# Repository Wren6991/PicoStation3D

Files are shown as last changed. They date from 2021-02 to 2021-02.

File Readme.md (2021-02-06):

PicoStation 3D
==============

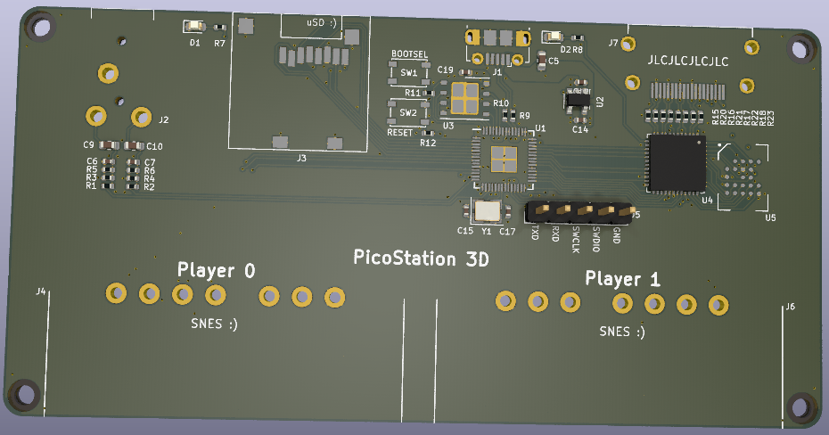
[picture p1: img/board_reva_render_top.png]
Top view of board, showing an RP2040 microcontroller, iCE40 UP5k FPGA, 8MB HyperRAM, HDMI socket, micro SD receptacle, audio jack, two SNES controller ports, micro USB for power + data.


This is an **unfinished, untested** project to develop a 3D games console based on an RP2040 microcontroller and an iCE40 UP5k FPGA. Quick links:

- [Board Schematic (PDF)](board/picostation.pdf)
- [RP2040 Datasheet (PDF)](https://datasheets.raspberrypi.org/rp2040/rp2040-datasheet.pdf)
- [FPGA Datasheet (PDF)](http://www.latticesemi.com/-/media/LatticeSemi/Documents/DataSheets/iCE/iCE40-UltraPlus-Family-Data-Sheet.ashx)

From left to right, the components on the top edge are:

- A 3.5mm TRS audio jack, connected straight to RP2040 GPIOs via an RC filter (no separate audio supply on this board rev)
- A status LED for the RP2040
- A micro SD receptacle connected to the RP2040
- A micro USB socket providing power to the board, and code download and serial comms via the RP2040
- A status LED for the FPGA
- An HDMI socket for DVI-D video output, connected to the FPGA

The bottom edge has two SNES controller sockets. Also on the board is an 8MiB HyperRAM connected to the FPGA.

There is a RESET and BOOTSEL button for the RP2040, for quick firmware updates over USB, but the debug header (UART + SWD) is a better solution for iterating and developing code.

There are 12 wires connecting the FPGA to the microcontroller, one of them going from a GPOUT clock output on the RP2040 to a GB_IN global clock input pin on the UP5k. The intention is to use these for an 8 bit parallel bus with a free-running clock, a valid-ready handshake and an IRQ line, and for the UP5k to derive its internal clocks from the bus clock. This interface overlaps with the pins required to load the FPGA's internal configuration memory (and the RP2040 also has control of the UP5k's reset) so there is no separate external flash required for the UP5k.

Board Use Cases
---------------

- Run everything, including graphics routines, on RP2040, and use the UP5k as a parallel to DVI-D bridge -- [see here for a quick demo of some scanline blitting on RP2040](https://twitter.com/wren6991/status/1352983731661926401?s=20)

- Run everything, including a soft processor, on the UP5k, and use RP2040 as a surprisingly cost-effective USB-serial bridge, as well as for firmware upload. You'll need some kind of shell running on the RP2040 to provide audio and controller port access from the FPGA

- Run game logic, audio, controller access and SD card access on RP2040, put all the graphics hardware in the UP5k (with the local 8MB HyperRAM as VRAM, plus the UP5k's internal 128k SPRAM)

- Run 3D vertex-side operations on RP2040, and put 3D fragment-side hardware on the FPGA

Project Status
--------------

I've laid out a first iteration of the board, and have soldered up a prototype, but haven't had the chance to bring up the board or write any firmware, thanks to being a bit overloaded with the launch of RP2040 itself!

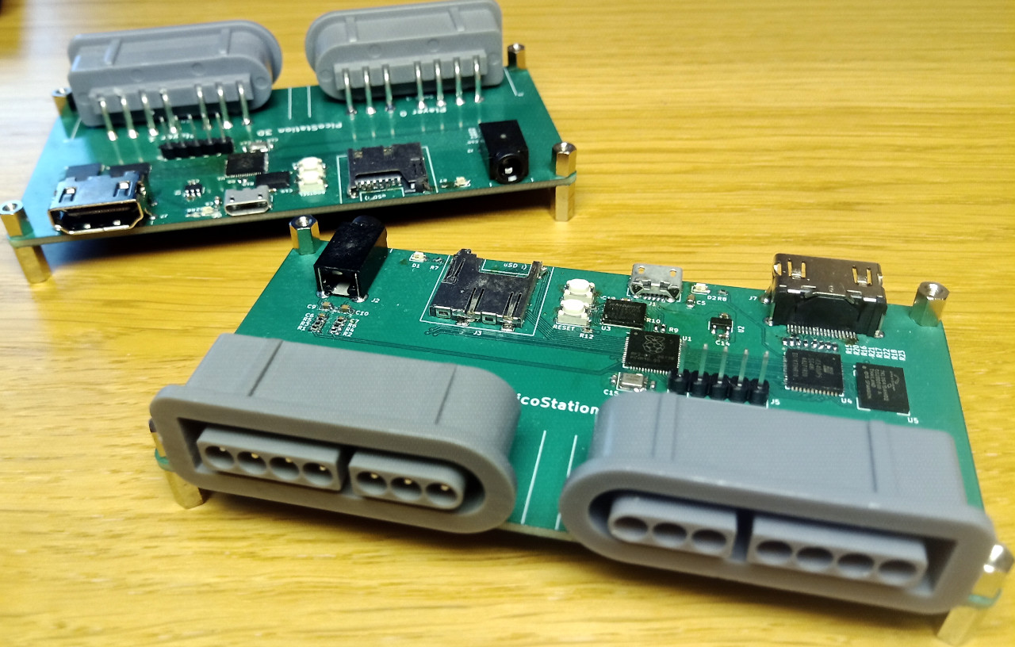
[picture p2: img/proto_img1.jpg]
Front view of a prototype board, showing the two SNES controller connectors soldered to the front


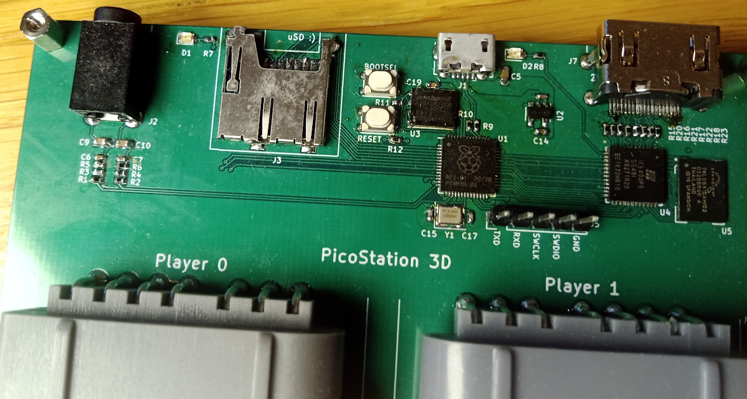
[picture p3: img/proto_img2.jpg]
Top detail of a prototype board, showing the RP2040 microcontroller, iCE40 UP5k FPGA, and HyperRAM. The controller ports are labelled player 0 and player 1.


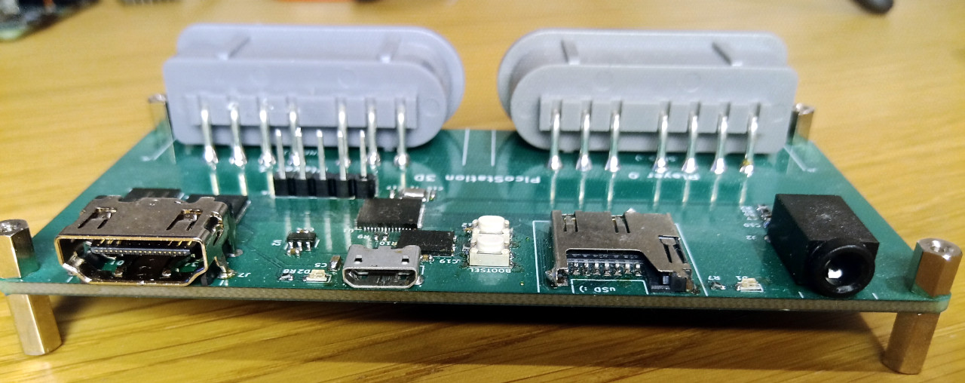
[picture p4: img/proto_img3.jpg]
Rear view of a prototype board, showing left to right the HDMI socket, FPGA LED, USB socket, SD card slot, microcontroller LED, and audio jack.


There are questionable decisions in [the schematic](board/picostation.pdf) (in particular the power chain violates the UP5k's sequencing requirements) so you shouldn't copy what you see here, but I'm posting this anyway because it might inspire somebody to make something better, and that is more important than me being embarrassed about my shoddy design work.

You can find a proof of concept for direct DVI output from a UP5k FPGA [in this repo](https://github.com/Wren6991/smoldvi).

I've also managed to squeeze [RISCBoy](https://github.com/Wren6991/RISCBoy) plus a DVI output onto a UP5k. Still need to push that code but you can see [a video of it I tweeted](https://twitter.com/wren6991/status/1348722305720004608?s=20). This shows you can fit plenty of interesting graphics hardware (and in this case a RISC-V processor) into a UP5k whilst generating DVI-D signals.

Known issues with rev A:

- Digital supply noise is audible through the audio jack. This could be improved by a separate LDO'd audio supply with a dual logic buffer, or just by deleting this output and doing digital audio through the video connector on the FPGA.
- The FPGA core supply comes from RP2040's LDO, to try and keep part count to an absolute minimum. This gives a fast ramp to 1.1 V shortly *after* the 3.3 V IO supply comes up, and a second ramp to 1.2 V some milliseconds later when software adjusts RP2040's core regulator. This is all quite questionable, and part of the point of Rev A is to find out whether I can get away with this.
- The controllers are only accessible from RP2040, not the FPGA. This is not a huge issue, but it would be more fun as an FPGA platform if they were moved to the FPGA, or perhaps even make the CLK and LAT line open-drain, and connect the controllers to both FPGA *and* RP2040.
- There is no separate configuration flash for the FPGA. Instead the microcontroller stores the bitstream in its flash, and writes this into the FPGA's configuration memory at boot. This should work fine but it's a less familiar development flow for those using this as an FPGA board, and it might be nice for pure-FPGA games consoles to have some local flash to access. Again, I'm trying to see how little hardware I can get away with, and this might have been a misstep.
- The SNES controller sockets are transposed left-to-right compared with an actual SNES.
- Double-sided component load makes it annoying to reflow this board at home, and adds cost if you want to get it PCBA'd.

If you have read all the way to the end and you have spotted something else that irritates you about this design, please [raise an issue!](/../../issues/) It will be a while until I get to Rev B. The main purpose of Rev A was to explore what I could get away with, and to develop the comms and interactions between microcontroller and FPGA.

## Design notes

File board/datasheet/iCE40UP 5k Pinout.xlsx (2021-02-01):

# Pin Out For iCE5UP5K (iCE40 UltraPlus - 5K)
# Revision 0.4 - Remove FWG49
# Revision 1.1 - Fix RGB pins, swapped C5 & A5 pins as well as 39 & 41
# Updated Jun 19, 2017
FNC | Pin Type | BANK | Differential Pair | UWG30 | SG48
IOB_0a | PIO | 2 |  | E5 | 46
IOB_2a | DPIO | 2 | TRUE_of_IOB_3b | D5 | 47
IOB_3b_G6 | DPIO/GBIN | 2 | COMP_of_IOB_2a | F5 | 44
IOB_4a | DPIO | 2 | TRUE_of_IOB_5b | - | 48
IOB_5b | DPIO | 2 | COMP_of_IOB_4a | - | 45
IOB_6a | PIO | 2 |  | - | 2
IOB_8a | DPIO | 2 | TRUE_of_IOB_9b | - | 4
IOB_9b | DPIO | 2 | COMP_of_IOB_8a | E4 | 3
IOB_10a | DPIO | 1 | TRUE_of_IOB_11b | C3 | -
IOB_11b_G5 | DPIO/GBIN | 1 | COMP_of_IOB_10a | F4 | -
creset_b | CONFIG | 1 |  | F3 | 8
IOB_12a_G4_CDONE | CONFIG/DPIO/GBIN | 1 | TRUE_of_IOB_13b | D3 | -
CDONE | CONFIG | 1 |  | - | 7
IOB_13b | DPIO | 1 | COMP_of_IOB_12a | E3 | 6
IOB_16a | PIO | 1 |  | - | 9
IOB_18a | PIO | 1 |  | - | 10
IOB_20a | PIO | 1 |  | - | 11
IOB_22a | DPIO | 1 | TRUE_of_IOB_23b | - | 12
IOB_23b | DPIO | 1 | COMP_of_IOB_22a | - | 21
IOB_24a | DPIO | 1 | TRUE_of_IOB_25b | B1 | 13
IOB_25b_G3 | DPIO/GBIN | 1 | COMP_of_IOB_24a | F2 | 20
IOB_29b | PIO | 1 |  | - | 19
IOB_31b | PIO | 1 |  | - | 18
IOB_32a_SPI_SO | DPIO/CONFIG_SPI | 1 |  | F1 | 14
IOB_33b_SPI_SI | DPIO/CONFIG_SPI | 1 |  | E1 | 17
IOB_34a_SPI_SCK | DPIO/CONFIG_SPI | 1 |  | D1 | 15
IOB_35b_SPI_SS | DPIO/CONFIG_SPI | 1 |  | C1 | 16
VCCPLL | VCCPLL |  |  | B2 | 29
IOT_36b | DPIO/I3C | 0 | COMP_of_IOT_37a | A1 | 25
IOT_37a | DPIO/I3C | 0 | TRUE_of_IOT_36b | A2 | 23
IOT_38b | DPIO | 0 | COMP_of_IOT_39a | - | 27
IOT_39a | DPIO | 0 | TRUE_of_IOT_38b | - | 26
IOT_41a | PIO | 0 |  | - | 28
IOT_42b | DPIO | 0 | COMP_of_IOT_43a | - | 31
IOT_43a | DPIO | 0 | TRUE_of_IOT_42b | - | 32
IOT_44b | DPIO | 0 | COMP_of_IOT_45a | - | 34
IOT_45a_G1 | DPIO/GBIN | 0 | TRUE_of_IOT_44b | - | 37
IOT_46b_G0 | DPIO/GBIN | 0 |  | B3 | 35
IOT_47a | PIO | 0 |  | A4 | -
IOT_48b | DPIO | 0 | COMP_of_IOT_49a | - | 36
IOT_49a | DPIO | 0 | TRUE_of_IOT_48b | - | 43
IOT_50b | DPIO | 0 | COMP_of_IOT_51a | - | 38
IOT_51a | DPIO | 0 | TRUE_of_IOT_50b | - | 42
RGB2 | LED | 0 |  | C5 | 41
RGB1 | LED | 0 |  | B5 | 40
RGB0 | LED | 0 |  | A5 | 39
GND | GND | GND |  | B4 | Paddle
GND | GND | GND |  | E2 | Paddle
GND | GND | GND |  | - | Paddle
VCC | VCC | VCC |  | C2 | 5
VCC | VCC | VCC |  | - | 30
VCCIO_0 | VCCIO | 0 |  | A3 | 33
SPI_Vccio1 | VCCIO | 1 |  | D2 | 22
VCCIO_2 | VCCIO | 2 |  | C4 | 1
VPP_2V5 | VPP | VPP |  | D4 | 24
*SG48 GND is connected to package paddle

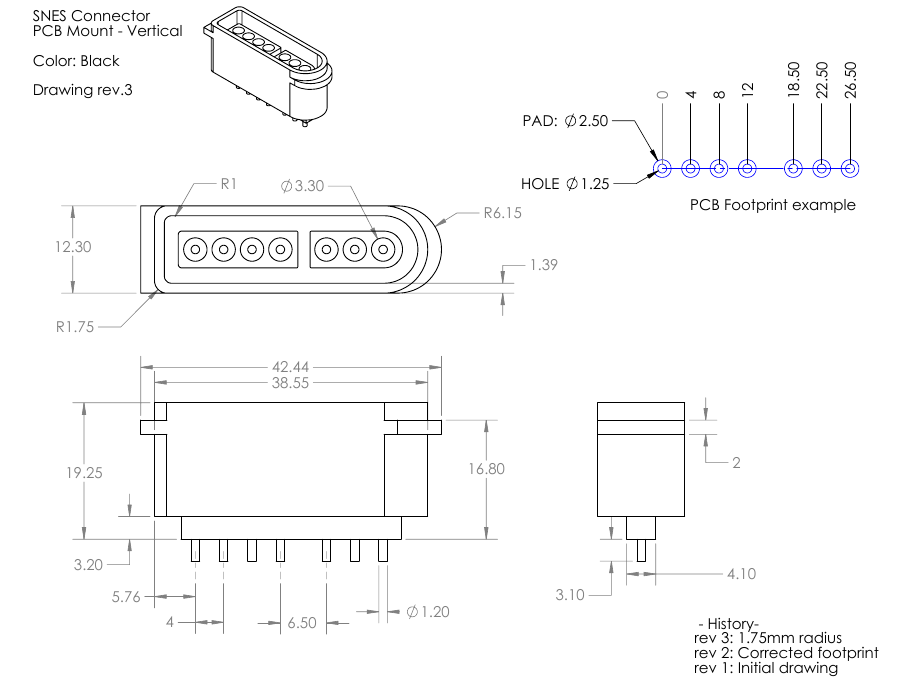
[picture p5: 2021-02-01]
board/datasheet/snes_connector_drawing.png

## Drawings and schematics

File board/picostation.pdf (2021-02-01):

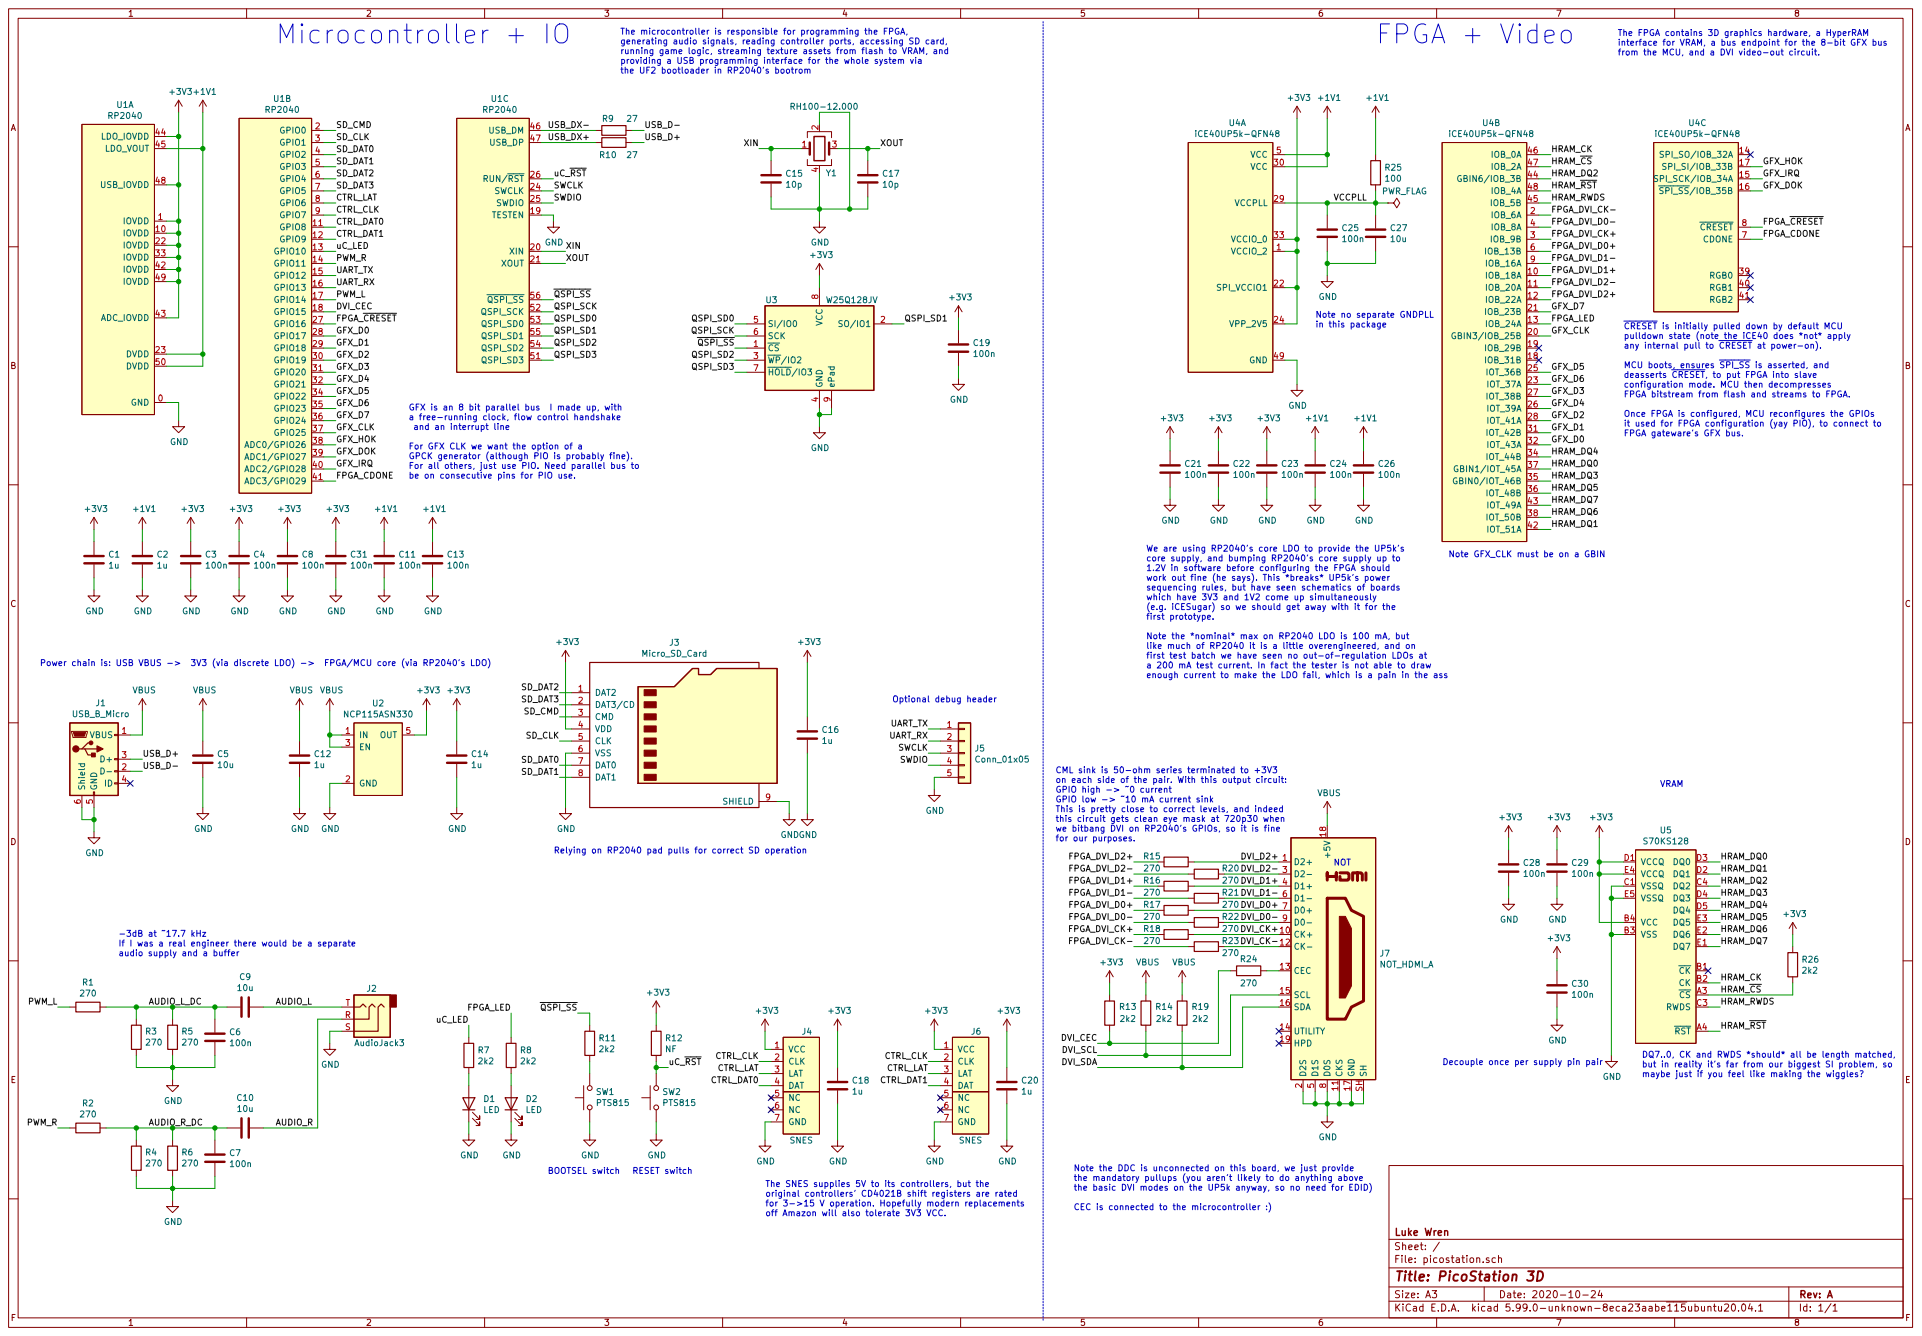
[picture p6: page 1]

The microcontroller is responsible for programming the FPGA,
generating audio signals, reading controller ports, accessing SD card,
running game logic, streaming texture assets from flash to VRAM, and
providing a USB programming interface for the whole system via
the UF2 bootloader in RP2040's bootrom

The FPGA contains 3D graphics hardware, a HyperRAM
interface for VRAM, a bus endpoint for the 8-bit GFX bus
from the MCU, and a DVI video-out circuit.

GND
Note no separate GNDPLL
in this package

4 SI/IO0 5 SCK 6 ~HOLD~/IO3 7 VCC

~CRESET~ is initially pulled down by default MCU
pulldown state (note the iCE40 does *not* apply
any internal pull to ~CRESET~ at power-on). MCU boots, ensures ~SPI_SS~ is asserted, and

deasserts ~CRESET~, to put FPGA into slave
configuration mode. MCU then decompresses FPGA bitstream from flash and streams to FPGA. Once FPGA is configured, MCU reconfigures the GPIOs

GFX is an 8 bit parallel bus I made up, with
a free-running clock, flow control handshake
and an interrupt line

it used for FPGA configuration (yay PIO), to connect to
FPGA gateware's GFX bus.

For GFX CLK we want the option of a
GPCK generator (although PIO is probably fine).
For all others, just use PIO. Need parallel bus to
be on consecutive pins for PIO use.

We are using RP2040's core LDO to provide the UP5k's
core supply, and bumping RP2040's core supply up to
1.2V in software before configuring the FPGA should
work out fine (he says). This *breaks* UP5k's power
sequencing rules, but have seen schematics of boards
which have 3V3 and 1V2 come up simultaneously
(e.g. iCESugar) so we should get away with it for the
first prototype. Note the *nominal* max on RP2040 LDO is 100 mA, but

like much of RP2040 it is a little overengineered, and on
first test batch we have seen no out-of-regulation LDOs at a 200 mA test current. In fact the tester is not able to draw

Power chain is: USB VBUS -> 3V3 (via discrete LDO) -> FPGA/MCU core (via RP2040's LDO)

enough current to make the LDO fail, which is a pain in the ass

CML sink is 50-ohm series terminated to +3V3
on each side of the pair. With this output circuit:
GPIO high -> ~~0 current GPIO low -> ~~10 mA current sink This is pretty close to correct levels, and indeed
VBUS R15

maybe just if you feel like making the wiggles? VRAM

this circuit gets clean eye mask at 720p30 when
we bitbang DVI on RP2040's GPIOs, so it is fine
for our purposes.
FPGA_DVI_D2+

Relying on RP2040 pad pulls for correct SD operation

-3dB at ~~17.7 kHz
If I was a real engineer there would be a separate

but in reality it's far from our biggest SI problem, so

Note the DDC is unconnected on this board, we just provide
the mandatory pullups (you aren't likely to do anything above
the basic DVI modes on the UP5k anyway, so no need for EDID)

The SNES supplies 5V to its controllers, but the
original controllers' CD4021B shift registers are rated

CEC is connected to the microcontroller :)

File: picostation.sch Sheet: / Luke Wren

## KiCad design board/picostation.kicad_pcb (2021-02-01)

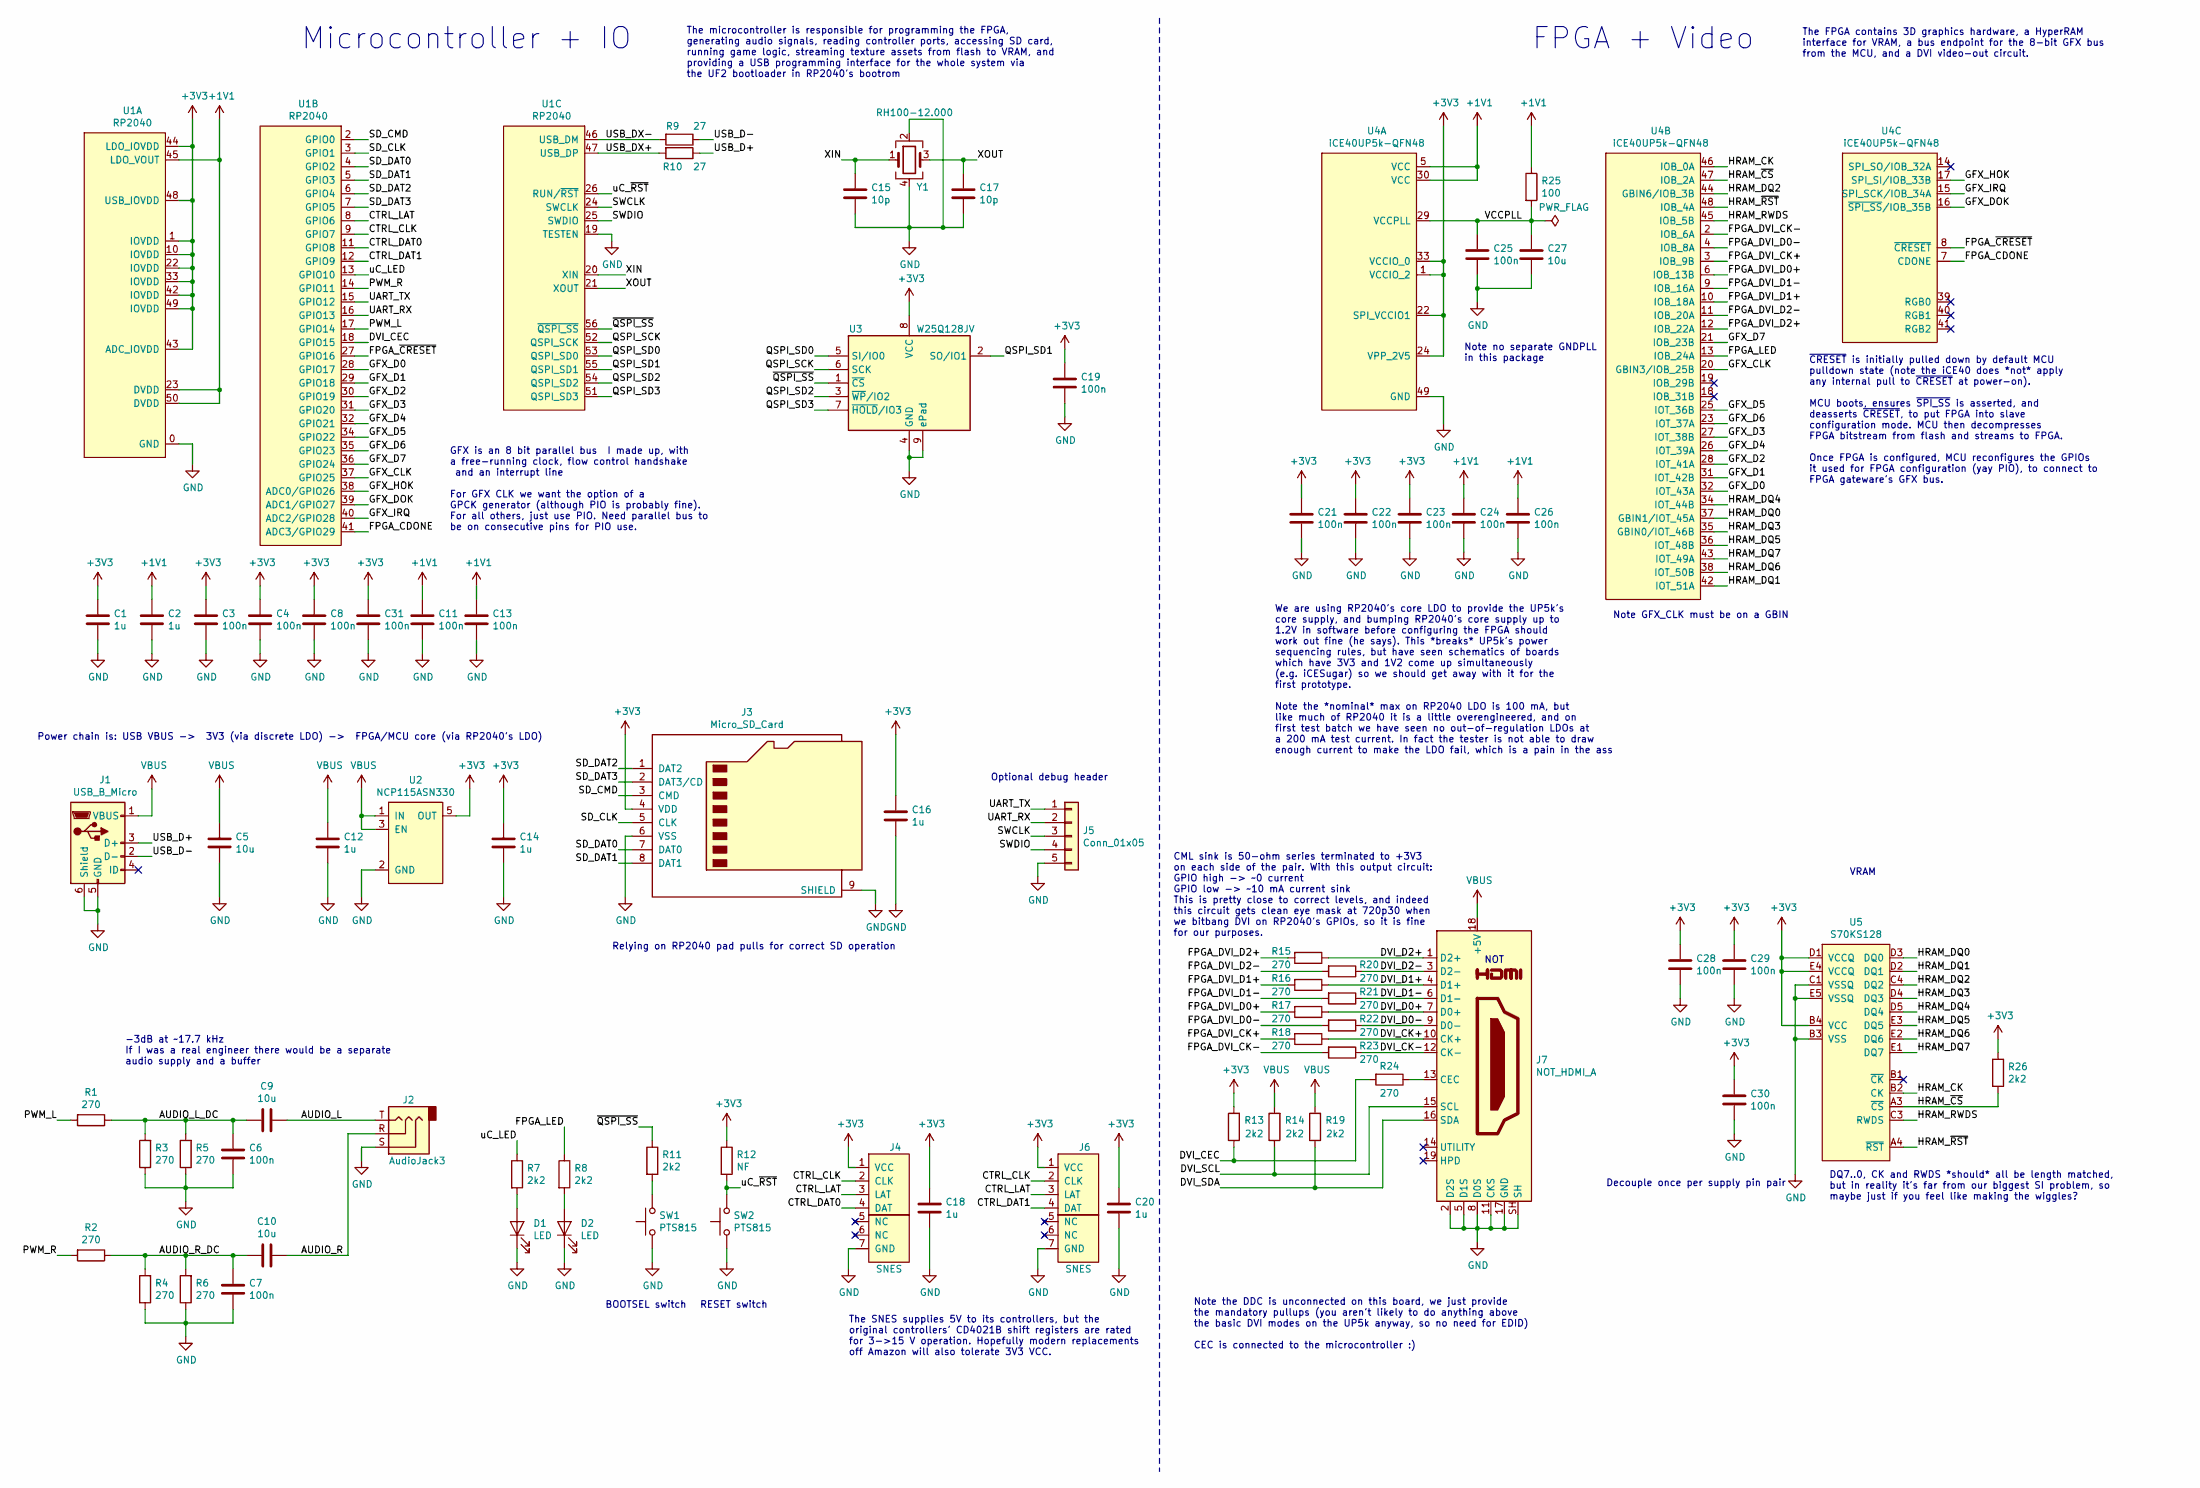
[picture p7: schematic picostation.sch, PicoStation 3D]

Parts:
C1, C2, C12, C14, C16, C18, C20: 1u; C_0402_1005Metric
C3, C4, C6, C7, C8, C11, C13, C19, C21, C22, C23, C24, C25, C26, C28, C29, C30, C31: 100n; C_0402_1005Metric
C5, C9, C10, C27: 10u; C_0603_1608Metric
C15, C17: 10p; C_0402_1005Metric
D1, D2: LED; LED_0603_1608Metric
J1: USB_B_Micro; USB_Micro-B_Molex-105017-0001
J2: AudioJack3; STX-3000-TRS
J3: Micro_SD_Card; MEM2061-MICRO-SD
J4: SNES; SNES-Controller-Right
J5: Conn_01x05; PinHeader_1x05_P2.54mm_Vertical
J6: SNES; SNES-Controller-Left
J7: NOT_HDMI_A; HDMI-SS-53000
R1, R2, R3, R4, R5, R6, R15, R16, R17, R18, R20, R21, R22, R23, R24: 270; R_0402_1005Metric
R7, R8, R11, R13, R14, R19, R26: 2k2; R_0402_1005Metric
R9, R10: 27; R_0402_1005Metric
R12: NF; R_0402_1005Metric
R25: 100; R_0402_1005Metric
SW1, SW2: PTS815; SW_SPST_PTS815
U1: RP2040; QFN-56_EP_7x7_Pitch0.4mm
U2: NCP115ASN330; SOT-23-5
U3: W25Q128JV; WSON-8-1EP_6x5mm_P1.27mm_EP3.4x4mm
U4: iCE40UP5k-QFN48; QFN-48-1EP_7x7mm_P0.5mm_EP5.3x5.3mm
U5: S70KS128
Y1: RH100-12.000; Crystal_SMD_3225-4Pin_3.2x2.5mm

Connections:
+1V1: C2.1, C11.1, C13.1, C24.1, C26.1, R25.1, U1.23 (DVDD), U1.45 (LDO_VOUT), U1.50 (DVDD), U4.5 (VCC), U4.30 (VCC)
+3V3: C1.1, C3.1, C4.1, C8.1, C14.1, C16.1, C18.1, C19.1, C20.1, C21.1, C22.1, C23.1, C28.1, C29.1, C30.1, C31.1, J3.4 (VDD), J4.1 (VCC), J6.1 (VCC), R12.1, R13.2, R26.1, U1.1 (IOVDD), U1.10 (IOVDD), U1.22 (IOVDD), U1.33 (IOVDD), U1.42 (IOVDD), U1.43 (ADC_IOVDD), U1.44 (LDO_IOVDD), U1.48 (USB_IOVDD), U1.49 (IOVDD), U2.5 (OUT), U3.8 (VCC), U4.1 (VCCIO_2), U4.22 (SPI_VCCIO1), U4.24 (VPP_2V5), U4.33 (VCCIO_0), U5.B4 (VCC), U5.D1 (VCCQ), U5.E4 (VCCQ)
/AUDIO_L: C9.1, J2.T
/AUDIO_L_DC: C6.1, C9.2, R1.1, R3.2, R5.2
/AUDIO_R: C10.1, J2.R
/AUDIO_R_DC: C7.1, C10.2, R2.1, R4.2, R6.2
/CTRL_CLK: J4.2 (CLK), J6.2 (CLK), U1.9 (GPIO7)
/CTRL_DAT0: J4.4 (DAT), U1.11 (GPIO8)
/CTRL_DAT1: J6.4 (DAT), U1.12 (GPIO9)
/CTRL_LAT: J4.3 (LAT), J6.3 (LAT), U1.8 (GPIO6)
/DVI_CEC: R13.1, R24.2, U1.18 (GPIO15)
/DVI_CK+: J7.10 (CK+), R18.1
/DVI_CK-: J7.12 (CK-), R23.1
/DVI_D0+: J7.7 (D0+), R17.1
/DVI_D0-: J7.9 (D0-), R22.1
/DVI_D1+: J7.4 (D1+), R16.1
/DVI_D1-: J7.6 (D1-), R21.1
/DVI_D2+: J7.1 (D2+), R15.1
/DVI_D2-: J7.3 (D2-), R20.1
/DVI_SCL: J7.15 (SCL), R14.1
/DVI_SDA: J7.16 (SDA), R19.1
/FPGA_CDONE: U1.41 (ADC3/GPIO29), U4.7 (CDONE)
/FPGA_DVI_CK+: R18.2, U4.3 (IOB_9B)
/FPGA_DVI_CK-: R23.2, U4.2 (IOB_6A)
/FPGA_DVI_D0+: R17.2, U4.6 (IOB_13B)
/FPGA_DVI_D0-: R22.2, U4.4 (IOB_8A)
/FPGA_DVI_D1+: R16.2, U4.10 (IOB_18A)
/FPGA_DVI_D1-: R21.2, U4.9 (IOB_16A)
/FPGA_DVI_D2+: R15.2, U4.12 (IOB_22A)
/FPGA_DVI_D2-: R20.2, U4.11 (IOB_20A)
/FPGA_LED: R8.1, U4.13 (IOB_24A)
/FPGA_~CRESET~: U1.27 (GPIO16), U4.8 (~CRESET~)
/GFX_CLK: U1.37 (GPIO25), U4.20 (GBIN3/IOB_25B)
/GFX_D0: U1.28 (GPIO17), U4.32 (IOT_43A)
/GFX_D1: U1.29 (GPIO18), U4.31 (IOT_42B)
/GFX_D2: U1.30 (GPIO19), U4.28 (IOT_41A)
/GFX_D3: U1.31 (GPIO20), U4.27 (IOT_38B)
/GFX_D4: U1.32 (GPIO21), U4.26 (IOT_39A)
/GFX_D5: U1.34 (GPIO22), U4.25 (IOT_36B)
/GFX_D6: U1.35 (GPIO23), U4.23 (IOT_37A)
/GFX_D7: U1.36 (GPIO24), U4.21 (IOB_23B)
/GFX_DOK: U1.39 (ADC1/GPIO27), U4.16 (~SPI_SS~/IOB_35B)
/GFX_HOK: U1.38 (ADC0/GPIO26), U4.17 (SPI_SI/IOB_33B)
/GFX_IRQ: U1.40 (ADC2/GPIO28), U4.15 (SPI_SCK/IOB_34A)
/HRAM_CK: U4.46 (IOB_0A), U5.B2 (CK)
/HRAM_DQ0: U4.37 (GBIN1/IOT_45A), U5.D3 (DQ0)
/HRAM_DQ1: U4.42 (IOT_51A), U5.D2 (DQ1)
/HRAM_DQ2: U4.44 (GBIN6/IOB_3B), U5.C4 (DQ2)
/HRAM_DQ3: U4.35 (GBIN0/IOT_46B), U5.D4 (DQ3)
/HRAM_DQ4: U4.34 (IOT_44B), U5.D5 (DQ4)
/HRAM_DQ5: U4.36 (IOT_48B), U5.E3 (DQ5)
/HRAM_DQ6: U4.38 (IOT_50B), U5.E2 (DQ6)
/HRAM_DQ7: U4.43 (IOT_49A), U5.E1 (DQ7)
/HRAM_RWDS: U4.45 (IOB_5B), U5.C3 (RWDS)
/HRAM_~CS~: R26.2, U4.47 (IOB_2A), U5.A3 (~CS~)
/HRAM_~RST~: U4.48 (IOB_4A), U5.A4 (~RST~)
/PWM_L: R1.2, U1.17 (GPIO14)
/PWM_R: R2.2, U1.14 (GPIO11)
/QSPI_SCK: U1.52 (QSPI_SCK), U3.6 (SCK)
/QSPI_SD0: U1.53 (QSPI_SD0), U3.5 (SI/IO0)
/QSPI_SD1: U1.55 (QSPI_SD1), U3.2 (SO/IO1)
/QSPI_SD2: U1.54 (QSPI_SD2), U3.3 (~WP~/IO2)
/QSPI_SD3: U1.51 (QSPI_SD3), U3.7 (~HOLD~/IO3)
/SD_CLK: J3.5 (CLK), U1.3 (GPIO1)
/SD_CMD: J3.3 (CMD), U1.2 (GPIO0)
/SD_DAT0: J3.7 (DAT0), U1.4 (GPIO2)
/SD_DAT1: J3.8 (DAT1), U1.5 (GPIO3)
/SD_DAT2: J3.1 (DAT2), U1.6 (GPIO4)
/SD_DAT3: J3.2 (DAT3/CD), U1.7 (GPIO5)
/SWCLK: J5.3, U1.24 (SWCLK)
/SWDIO: J5.4, U1.25 (SWDIO)
/UART_RX: J5.2, U1.16 (GPIO13)
/UART_TX: J5.1, U1.15 (GPIO12)
/USB_D+: J1.3 (D+), R10.1
/USB_D-: J1.2 (D-), R9.1
/USB_DX+: R10.2, U1.47 (USB_DP)
/USB_DX-: R9.2, U1.46 (USB_DM)
/VCCPLL: C25.1, C27.1, R25.2, U4.29 (VCCPLL)
/XIN: C15.1, U1.20 (XIN), Y1.1
/XOUT: C17.1, U1.21 (XOUT), Y1.3
/uC_LED: R7.1, U1.13 (GPIO10)
/uC_~RST~: R12.2, SW2.2, U1.26 (RUN/~RST~)
/~QSPI_SS~: R11.1, U1.56 (~QSPI_SS~), U3.1 (~CS)
GND: C1.2, C2.2, C3.2, C4.2, C5.2, C6.2, C7.2, C8.2, C11.2, C12.2, C13.2, C14.2, C15.2, C16.2, C17.2, C18.2, C19.2, C20.2, C21.2, C22.2, C23.2, C24.2, C25.2, C26.2, C27.2, C28.2, C29.2, C30.2, C31.2, D1.1 (K), D2.1 (K), J1.5 (GND), J1.6 (Shield), J2.S, J3.6 (VSS), J3.9 (SHIELD), J4.7 (GND), J5.5, J6.7 (GND), J7.2 (D2S), J7.5 (D1S), J7.8 (D0S), J7.11 (CKS), J7.17 (GND), J7.SH, R3.1, R4.1, R5.1, R6.1, SW1.1, SW2.1, U1.0 (GND), U1.19 (TESTEN), U2.2 (GND), U3.4 (GND), U3.9 (ePad), U4.49 (GND), U5.B3 (VSS), U5.C1 (VSSQ), U5.E5 (VSSQ), Y1.2, Y1.4
unnamed: D1.2 (A), R7.2
unnamed: D2.2 (A), R8.2
unnamed: J7.13 (CEC), R24.1
unnamed: R11.2, SW1.2
VBUS: C5.1, C12.1, J1.1 (VBUS), J7.18 (+5V), R14.2, R19.2, U2.1 (IN), U2.3 (EN)

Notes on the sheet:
Decouple once per supply pin pair
DQ7..0, CK and RWDS *should* all be length matched, but in reality it's far from our biggest SI problem, so maybe just if you feel like making the wiggles?
Note no separate GNDPLL in this package
We are using RP2040's core LDO to provide the UP5k's core supply, and bumping RP2040's core supply up to 1.2V in software before configuring the FPGA should work out fine (he says). This *breaks* UP5k's power sequencing rules, but have seen schematics of boards which have 3V3 and 1V2 come up simult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
NOT
GFX is an 8 bit parallel bus I made up, with a free-running clock, flow control handshake and an interrupt line For GFX CLK we want the option of a GPCK generator (although PIO is probably fine). For all others, just use PIO. Need parallel bus to be on consecutive pins for PIO use.
BOOTSEL switch
RESET switch
-3dB at ~~17.7 kHz If I was a real engineer there would be a separate audio supply and a buffer
The SNES supplies 5V to its controllers, but the original controllers' CD4021B shift registers are rated for 3->15 V operation. Hopefully modern replacements off Amazon will also tolerate 3V3 VCC.
FPGA + Video
Microcontroller + IO
Power chain is: USB VBUS -> 3V3 (via discrete LDO) -> FPGA/MCU core (via RP2040's LDO)
~CRESET~ is initially pulled down by default MCU pulldown state (note the iCE40 does *not* apply any internal pull to ~CRESET~ at power-on). MCU boots, ensures ~SPI_SS~ is asserted, and deasserts ~CRESET~, to put FPGA into slave configuration mode. MCU then decompresses FPGA bitstream from flash an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
Relying on RP2040 pad pulls for correct SD operation
VRAM
CML sink is 50-ohm series terminated to +3V3 on each side of the pair. With this output circuit: GPIO high -> ~~0 current GPIO low -> ~~10 mA current sink This is pretty close to correct levels, and indeed this circuit gets clean eye mask at 720p30 when we bitbang DVI on RP2040's GPIOs, so it is fi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
The FPGA contains 3D graphics hardware, a HyperRAM interface for VRAM, a bus endpoint for the 8-bit GFX bus from the MCU, and a DVI video-out circuit.
The microcontroller is responsible for programming the FPGA, generating audio signals, reading controller ports, accessing SD card, running game logic, streaming texture assets from flash to VRAM, and providing a USB programming interface for the whole system via the UF2 bootloader in RP2040's boot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
Optional debug header
Note GFX_CLK must be on a GBIN
Note the DDC is unconnected on this board, we just provide the mandatory pullups (you aren't likely to do anything above the basic DVI modes on the UP5k anyway, so no need for EDID) CEC is connected to the microcontroller :)

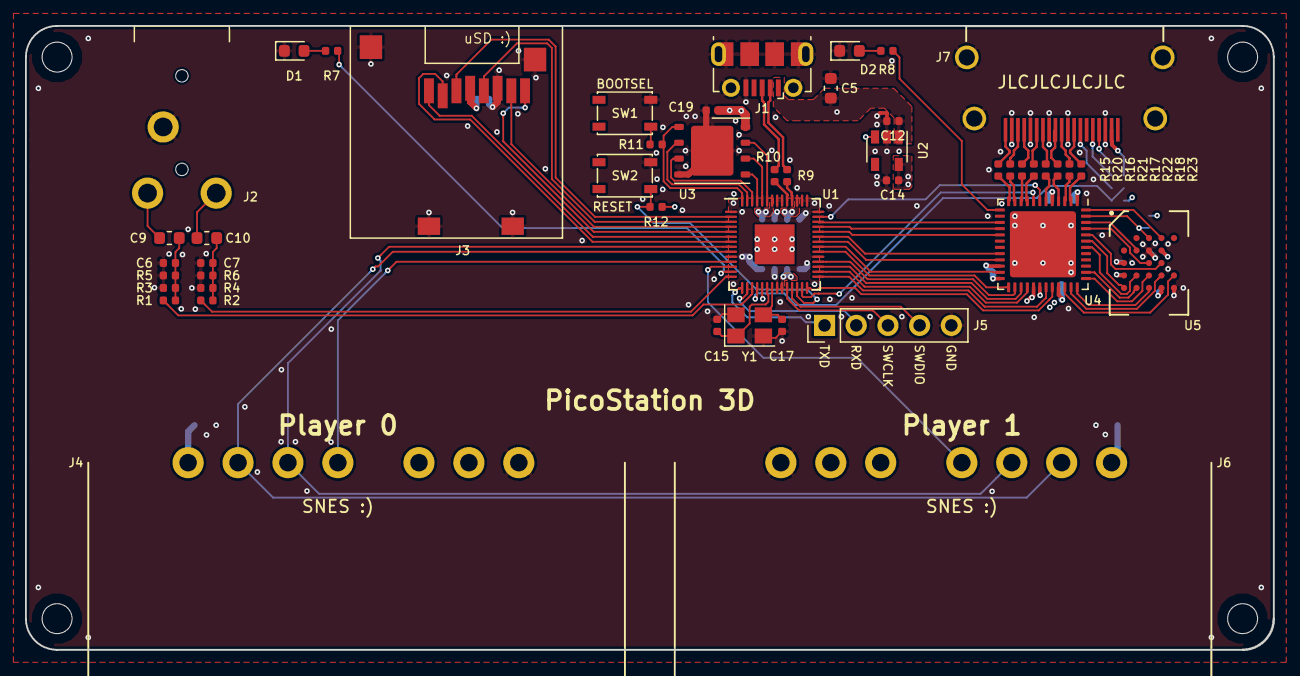
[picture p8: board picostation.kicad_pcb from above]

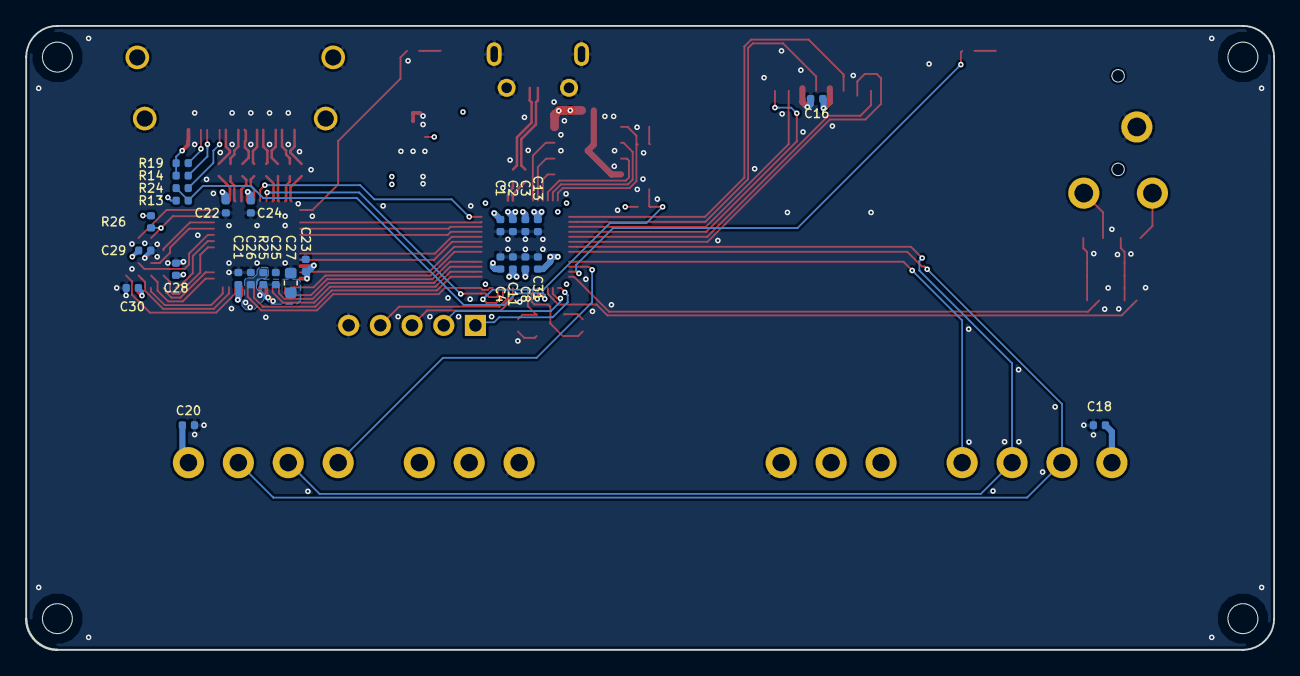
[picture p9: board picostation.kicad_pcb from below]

Board: 4 copper layers, 100.0 x 50.0 mm, 74 parts (27 on the bottom side), 89 nets.

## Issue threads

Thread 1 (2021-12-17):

On possible GPU on FPGA variants

mardab, 2021-12-17:
I like what you are planning to achieve with this project and from how I see it, this could serve as a way to determine what parts of similar project should stay on microcontroller or go to FPGA for desired results.

Beyond that, I see something that might as well be spun off into its own project, and that is microcontroller-class GPU/HMI accelerator. Granted, there is now a few microcontrollers with 2D accelerators or VGLite GPU, but they are on an expensive side and are more specialized towards HMI.

There are at least 3 ways I can see this idea going forward:
* HMI "handler", drawing, displaying and responding to touch/physical controls, but only communicating with host when there is a need for information that's not present on flash chip storing code and assets for handler, or a command/information to that host inputted from using that HMI.
* 2D GPU controlled in [retained mode](https://en.wikipedia.org/wiki/Retained_mode), maybe even using its own asset storage like HMI handler.
* configurable GPU, that can have only what's required for a given application, driven with bitcode that only represents what was configured. I see a non-negligible possibility, that some configurations might only need something much smaller/cheaper than UP5K, maybe even cheaper than difference to neareast HMI-capable host chip.

I see that you haven't posted here for past 10 months, and aside from throwing this far-fetched idea, I would like to encourage you to continue work on this project either way. In my opinion there are 2 ways in which next board revisions could be improved:
* Wire one SNES controller socket to MCU, other to FPGA, then have almost all other components duplicated, so that you could have them wired in the same fashion, and be able to test different use cases and configurations without having to redesign and respin board.
* Displace RP2040 with NXP i.MX RT106x (Teensy 4.x's chip). I understand that by doing so it won't be much of a **Pico**Station anymore, but then Pico still could act as the very flexible control and I/O processor, while Station will get much more performant core with 2D acceleration and dedicated video output AND input, allowing for even more possibilites for experimentation (e.g. early 3dfx Voodoo-style 3D acceleration in FPGA)

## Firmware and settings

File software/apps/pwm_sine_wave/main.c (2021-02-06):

#include <math.h>

#include "pico/stdlib.h"
#include "hardware/pwm.h"
#include "hardware/vreg.h"
#include "hardware/irq.h"

#define CORE_VOLTAGE VREG_VOLTAGE_1_20
#define SYS_CLOCK_KHZ 252000
#define SAMPLE_CLOCK_KHZ 48
#define SAMPLE_BITS 12

static_assert(SYS_CLOCK_KHZ % SAMPLE_CLOCK_KHZ == 0, "Audio clock must divide system clock");
static_assert(1 << SAMPLE_BITS < SYS_CLOCK_KHZ / SAMPLE_CLOCK_KHZ, "Samples larger than PWM period");
static_assert(1 << SAMPLE_BITS >= SYS_CLOCK_KHZ / SAMPLE_CLOCK_KHZ / 2, "Samples less than half of PWM period");

// Range 0 to 0xfff
static uint16_t __time_critical_func(sine_table)[256] = {
	0x800,  0x832,  0x864,  0x896,  0x8c8,  0x8fa,  0x92c,  0x95e,  0x98f,  0x9c0,
	0x9f1,  0xa22,  0xa52,  0xa82,  0xab1,  0xae1,  0xb0f,  0xb3d,  0xb6b,
	0xb98,  0xbc5,  0xbf1,  0xc1c,  0xc47,  0xc71,  0xc9b,  0xcc3,  0xceb,  0xd13,
	0xd39,  0xd5f,  0xd84,  0xda8,  0xdcb,  0xded,  0xe0e,  0xe2f,  0xe4e,
	0xe6c,  0xe8a,  0xea6,  0xec2,  0xedc,  0xef5,  0xf0e,  0xf25,  0xf3b,  0xf50,
	0xf64,  0xf76,  0xf88,  0xf98,  0xfa7,  0xfb5,  0xfc2,  0xfce,  0xfd8,
	0xfe1,  0xfe9,  0xff0,  0xff6,  0xffa,  0xffd,  0xfff,  0xfff,  0xfff,
	0xffd,  0xffa,  0xff6,  0xff0,  0xfe9,  0xfe1,  0xfd8,  0xfce,  0xfc2,  0xfb5,
	0xfa7,  0xf98,  0xf88,  0xf76,  0xf64,  0xf50,  0xf3b,  0xf25,  0xf0e,
	0xef5,  0xedc,  0xec2,  0xea6,  0xe8a,  0xe6c,  0xe4e,  0xe2f,  0xe0e,  0xded,
	0xdcb,  0xda8,  0xd84,  0xd5f,  0xd39,  0xd13,  0xceb,  0xcc3,  0xc9b,
	0xc71,  0xc47,  0xc1c,  0xbf1,  0xbc5,  0xb98,  0xb6b,  0xb3d,  0xb0f,  0xae1,
	0xab1,  0xa82,  0xa52,  0xa22,  0x9f1,  0x9c0,  0x98f,  0x95e,  0x92c,
	0x8fa,  0x8c8,  0x896,  0x864,  0x832,  0x800,  0x7cd,  0x79b,  0x769,  0x737,
	0x705,  0x6d3,  0x6a1,  0x670,  0x63f,  0x60e,  0x5dd,  0x5ad,  0x57d,
	0x54e,  0x51e,  0x4f0,  0x4c2,  0x494,  0x467,  0x43a,  0x40e,  0x3e3,  0x3b8,
	0x38e,  0x364,  0x33c,  0x314,  0x2ec,  0x2c6,  0x2a0,  0x27b,  0x257,
	0x234,  0x212,  0x1f1,  0x1d0,  0x1b1,  0x193,  0x175,  0x159,  0x13d,  0x123,
	0x10a,  0x0f1,  0x0da,  0x0c4,  0x0af,  0x09b,  0x089,  0x077,  0x067,
	0x058,  0x04a,  0x03d,  0x031,  0x027,  0x01e,  0x016,  0x00f,  0x009,  0x005,
	0x002,  0x000,  0x000,  0x000,  0x002,  0x005,  0x009,  0x00f,  0x016,
	0x01e,  0x027,  0x031,  0x03d,  0x04a,  0x058,  0x067,  0x077,  0x089,  0x09b,
	0x0af,  0x0c4,  0x0da,  0x0f1,  0x10a,  0x123,  0x13d,  0x159,  0x175,
	0x193,  0x1b1,  0x1d0,  0x1f1,  0x212,  0x234,  0x257,  0x27b,  0x2a0,  0x2c6,
	0x2ec,  0x314,  0x33c,  0x364,  0x38e,  0x3b8,  0x3e3,  0x40e,  0x43a,
	0x467,  0x494,  0x4c2,  0x4f0,  0x51e,  0x54e,  0x57d,  0x5ad,  0x5dd,  0x60e,
	0x63f,  0x670,  0x6a1,  0x6d3,  0x705,  0x737,  0x769,  0x79b,  0x7cd
};

#define C4 261.63f
#define D4 293.66f
#define E4 329.63f
#define F4 349.23f
#define G4 392.00f
#define A4 440.00f
#define B4 493.88f

const struct {float freq_hz; uint duration_ms;} song[] = {
	{C4    , 500 },
	{D4    , 500 },
	{E4    , 500 },
	{F4    , 500 },
	{G4    , 500 },
	{A4    , 500 },
	{B4    , 500 },
	{C4 * 2, 500 },
	{0     , 1000},
};

static inline void pwm_set_both_channels(uint slice, uint16_t sample) {
	// 16 bit data gets replicated to 32 bits on the bus
	*(io_rw_16*)&pwm_hw->slice[slice].cc = sample;
}

uint audio_pwm_slice;
float note_freq_hz = 440;

void pwm_irq_handler() {
	pwm_clear_irq(audio_pwm_slice);

	// Let Pi = 128 :)
	static float theta = 0;
	theta += note_freq_hz * (256.f / (SAMPLE_CLOCK_KHZ * 1000));
	if (theta >= 256.f)
		theta -= 256.f;

	pwm_set_both_channels(audio_pwm_slice, sine_table[(uint8_t)theta]);
}


int main() {
	vreg_set_voltage(CORE_VOLTAGE);
	sleep_ms(1);
	set_sys_clock_khz(SYS_CLOCK_KHZ, true);

	audio_pwm_slice = pwm_gpio_to_slice_num(PICOSTATION_AUDIO_PWM_R_PIN);
	pwm_config c = pwm_get_default_config();
	pwm_config_set_wrap(&c, SYS_CLOCK_KHZ / SAMPLE_CLOCK_KHZ - 1);
	pwm_init(audio_pwm_slice, &c, false);
	pwm_set_both_channels(audio_pwm_slice, 1u << (SAMPLE_BITS - 1));

	pwm_clear_irq(audio_pwm_slice);
	pwm_set_irq_enabled(audio_pwm_slice, true);
	irq_set_exclusive_handler(PWM_IRQ_WRAP, pwm_irq_handler);


	gpio_set_function(PICOSTATION_AUDIO_PWM_R_PIN, GPIO_FUNC_PWM);
	pwm_set_enabled(audio_pwm_slice, true);
	irq_set_enabled(PWM_IRQ_WRAP, true);
	while (true) {
		for (int note = 0; note < count_of(song); ++note) {
			note_freq_hz = song[note].freq_hz;
			sleep_ms(song[note].duration_ms);
		}
	}
}

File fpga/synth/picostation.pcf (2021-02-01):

# Blink blonk
set_io led 13

# HyperRAM
set_io hram_clk   46
set_io hram_cs_n  47
set_io hram_rst_n 48
set_io hram_rwds  45
set_io hram_dq[0] 37
set_io hram_dq[1] 42
set_io hram_dq[2] 44
set_io hram_dq[3] 35
set_io hram_dq[4] 34
set_io hram_dq[5] 36
set_io hram_dq[6] 38
set_io hram_dq[7] 43

# GFX-bus host interface (including our main clock source)
set_io gfx_clk   20
set_io gfx_dok   16
set_io gfx_hok   17
set_io gfx_irq   15
set_io gfx_dq[0] 32
set_io gfx_dq[1] 31
set_io gfx_dq[2] 28
set_io gfx_dq[3] 27
set_io gfx_dq[4] 26
set_io gfx_dq[5] 25
set_io gfx_dq[6] 23
set_io gfx_dq[7] 21

# DVI interface (lane order {CLK, D2, D1, D0})
set_io dvi_p[3] 3
set_io dvi_n[3] 2
set_io dvi_p[2] 12
set_io dvi_n[2] 11
set_io dvi_p[1] 10
set_io dvi_n[1] 9
set_io dvi_p[0] 6
set_io dvi_n[0] 4

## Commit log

2021-02-06 Play with PWM audio
2021-02-14 Wrong pin number for CDONE
    [picostation.h]
2021-02-14 Plausible looking init sequence for UP5k. Still doesn't want to talk to me
    [main.c]
